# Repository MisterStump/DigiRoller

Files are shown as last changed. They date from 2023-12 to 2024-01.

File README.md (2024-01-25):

# DigiRoller

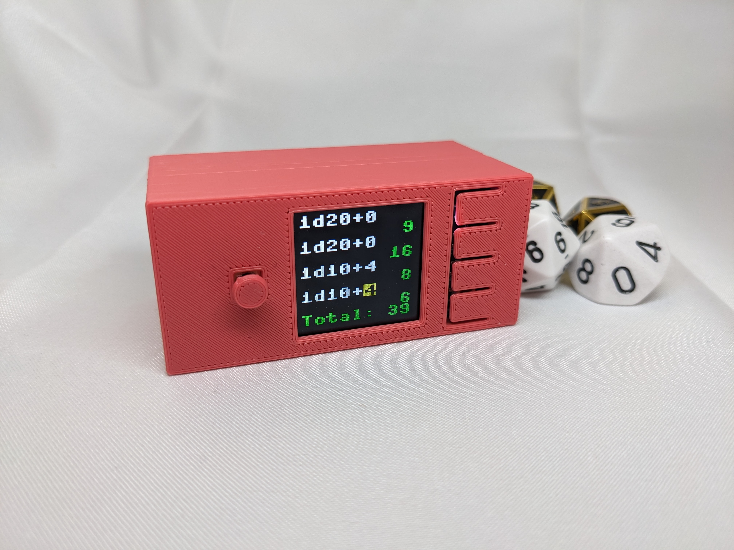
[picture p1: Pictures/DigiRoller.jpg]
DigiRoller


## What is it?
The DigiRoller is a Pico Pi powered pocket digital die roller designed for D&D/Tabletop gaming. Use it to make a handfull of simple rolls, or to roll a ton of dice all at once. I am posting this project because what got me into it was seeing all the other neat things people make. I wanted to maybe help inspire someone to try something too.

## How does it work?
There are 4 buttons, and a 4-way joystick
- Joytick up/down/left/right moves the cursor (the selection)
- First button rolls/rerolls
- Second button clears. If there are roll results those are cleared. If not, it resets all dice
- Third button increases the selected field
- Fourth button decreases the selected field

## Things you will need
- A 3D printer for the case
- A pico pi (https://www.waveshare.com/raspberry-pi-pico.htm)
- A pico 1.3" screen (https://www.waveshare.com/pico-lcd-1.3.htm)
- A pico USP power supply (https://www.waveshare.com/pico-ups-b.htm, the li-po one)

## Steps
- Once you have the pico, follow the instructions to set up Thonny so you can move code onto the pico: https://www.waveshare.com/wiki/Raspberry_Pi_Pico
- Move the 2 included .py files from the Code folder onto the pico
- Plug the screen in, following the guide: https://www.waveshare.com/wiki/Pico-LCD-1.3
- Plug the battery in, following the guide
- At this point, you should be able to unplug the Pico, turn on the UPS, and the battery roller code should work
- Now print the 3 case pieces.

## Print suggestions
I printed at a 0.2mm layer height. But each printer may have slightly different tolerances. You can use the Thingiverse Customizer for this project or the included OpenSCAD file to tweak the 'tolerance' settings.

## Final words
Good luck with the project!

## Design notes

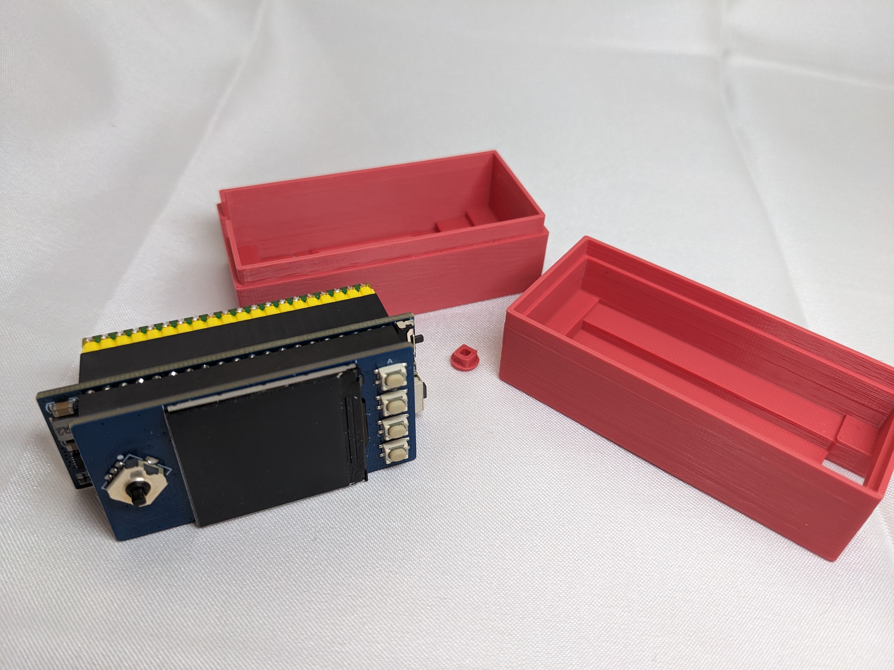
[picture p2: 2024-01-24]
Pictures/DigiRoller Bits.jpg

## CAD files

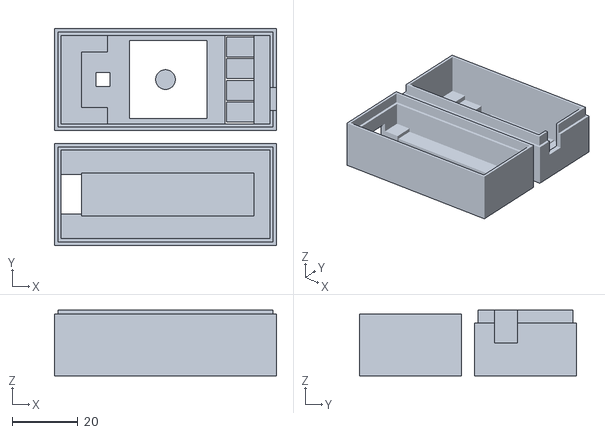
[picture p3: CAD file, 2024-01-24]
Case/all 3 pieces.stl
67.3 x 65.6 x 20.0

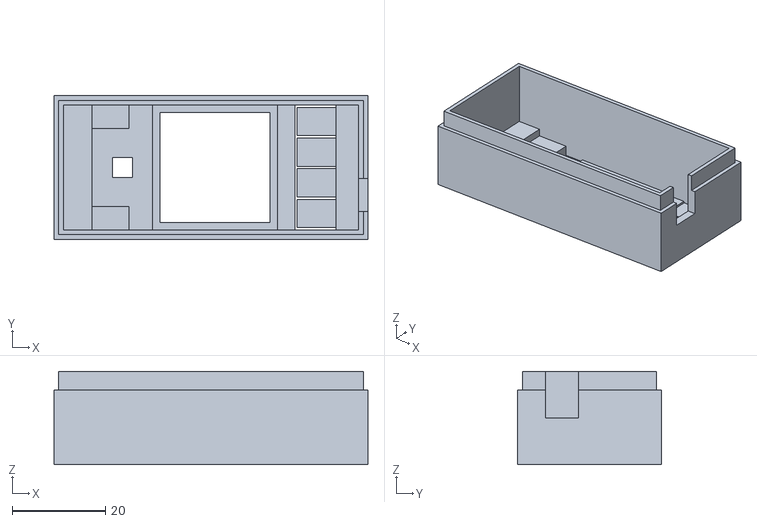
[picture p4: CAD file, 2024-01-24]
Case/top only.stl
67.3 x 30.8 x 20.0

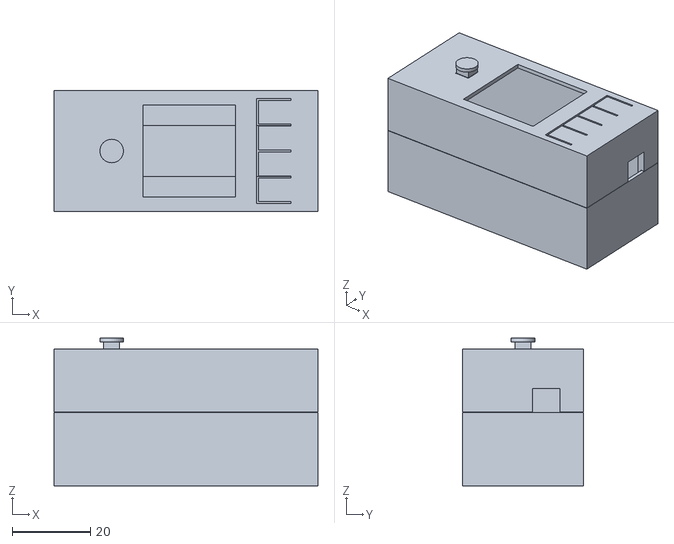
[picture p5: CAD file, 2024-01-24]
Case/demo - do not print.stl
67.3 x 30.8 x 37.7

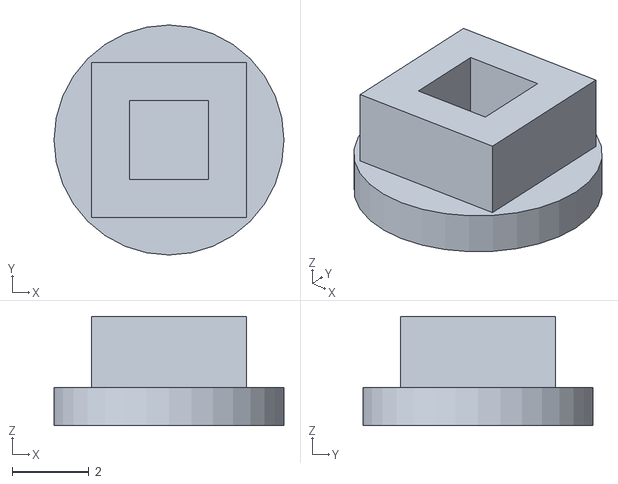
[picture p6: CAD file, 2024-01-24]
Case/joystick only.stl
6.00 x 6.00 x 2.85

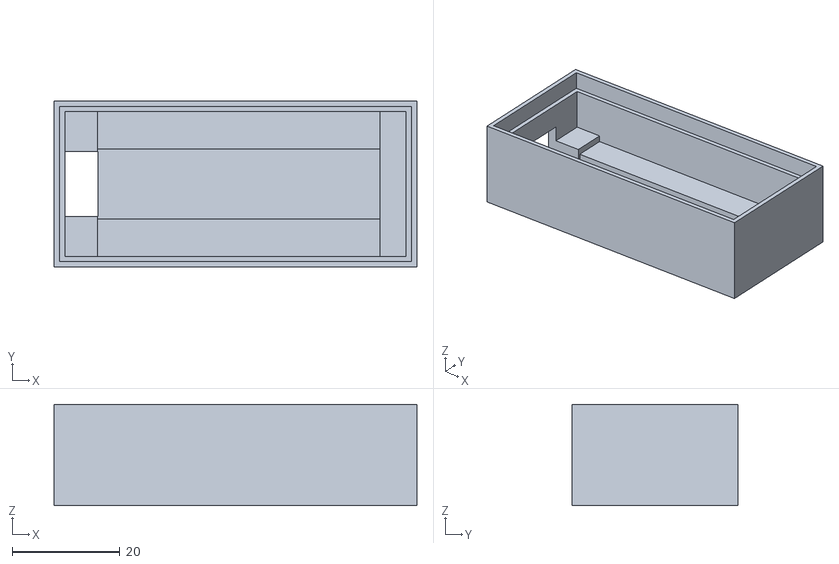
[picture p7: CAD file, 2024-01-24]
Case/bottom only.stl
67.3 x 30.8 x 18.8

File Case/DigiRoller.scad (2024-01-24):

// Digi Dice Roller - by MrStump
/*
Notes:
- Assuming you are looking head-on to the screen, then measurements are always:
    - x = left/right on screen
    - y = up/down on screen
    - z = the screen down to the battery back
- There are 3 models mentioned
    - Top Section = the upper body piece that includes the face
    - Bottom Section = the lower body piece that has the USB opening
    - Joystick = the little joystick nub that fits onto the 5-way switch
- Looking at the side, the module sections are:
    - ScreenSection = the screen all the way down to the UPS board
    - UPSSection = the battery board only, no pin sections
    - PicoSection = Everything below the UPS board, including the pin section
- The modules are oddly sided:
    - ScreenSection is larger in the Y than any other section
    - UPSSection is larger in the X than any other section
- The general layout of the code is:
    - Logic section determined what will be built and calls the Create module to make it
    - Create generates a whole printable piece using 1 or more Parts
    - Parts are individual fascets/conceptual elements of a model
*/


/////////////////////////////////////////////
// Parameters - things to modify to easilly change the model
/////////////////////////////////////////////

/* [General] */
//What part to print
Printed_Part = "All"; //[Top Section, Bottom Section, Joystick, All, Demo]
//How thick the face is. Impact look, as well as how stiff/flimsy buttons are
Face_Thickness = 0.6;
//How thickness of the thinnest part of walls
Wall_Thickness = 2;

/* [Tolerance offset so printed parts fit better] */
//How much X (left/right) to remove for the fitted parts
X_Tollerance = 0.3;
//How much Y (top of screen/bottom of screen) to remove for the fitted parts
Y_Tollerance = 0.3;
//How much Z (screen to back of case) to remove for the fitted parts
Z_Tollerance = 0.15;










//Prevents anything below this point showing in customizer
module customizerStop(){} customizerStop();


/////////////////////////////////////////////
// Hard-coded parameters - things to modify that are calculated or more delicate
/////////////////////////////////////////////

//Epsilon, prevent exact surface overlap during cutouts
eps = 0.007;
//Level of detail on rounded edges
$fn = 32;

//Measurements for the ScreenSection
//Circuit board measurements
ScreenSection_board_x = 52.25 + X_Tollerance;
ScreenSection_board_y = 26.52 + Y_Tollerance;
ScreenSection_board_z = 4.3;
//Pins (black plastic bit that connects ScreenSection to UPSSection)
ScreenSection_pins_x = 52.25 + X_Tollerance;
ScreenSection_pins_y = 20.15 + Y_Tollerance;
ScreenSection_pins_z = 9.8 - 0.45;

//Measurements for the UPSSection
//UPS board measurements (board only, not even counting circuits sticking up)
UPSSection_x = 63 + X_Tollerance;
UPSSection_y = 20.15 + Y_Tollerance;
UPSSection_z = 1.6 + Z_Tollerance;

//Max dimensions of interior space (where pico sits)
interiorMax_x = UPSSection_x;
interiorMax_y = ScreenSection_board_y;

//Measurements for the PicoSection
//Circuit board and circuits
PicoSection_board_x = 52.25 + X_Tollerance;
PicoSection_board_y = 20.95 + Y_Tollerance;
PicoSection_board_z = 2.8; //was 3.5
//Pins (black plastic bit that connects UPSSection to PicoSection)
PicoSection_pins_x = 52.25 + X_Tollerance;
PicoSection_pins_y = 20.95 + Y_Tollerance;
PicoSection_pins_z = 11.25;
//Amount above pins that the USB port is in the z
PicoSection_usb = 5.5; //THIS MAY BE WRONG
//Amount of upen air above the circuity
PicoSection_airGap_x = UPSSection_x;
PicoSection_airGap_y = 13; //in the center, this is the air space left
PicoSection_airGap_z = PicoSection_usb - PicoSection_board_z;

//UPS and Screen are not centered on the X. This is the additional excess
UPStoSCREEN_left = 6.11;
UPStoSCREEN_right = 4.88;
//Offset of Screen-To-UPS (it isn't quite centered on the X)
ScreenToUPSOffset_x = UPStoSCREEN_left - UPStoSCREEN_right - 0.6 + 0.2;

//Measurements of screen cutout
screenCut_x = 23.4 + X_Tollerance/2;
screenCut_y = 23.4 + Y_Tollerance/2;

//Measurements of joystick cutout
joyCut_x = 4 + X_Tollerance;
joyCut_y = 4 + Y_Tollerance;
//Distance from edge/center the joystick is positioned
joyCutDistance_fromEdge = 6.5;
joyCutDistance_fromCenter = ScreenSection_board_x/2 - joyCutDistance_fromEdge;

//Buttons X (y defined below)
button_x = 10;

//Space between each button
buttonCutWidth = 0.5;
//Measurements for buttons
buttonSecontion_x = button_x+buttonCutWidth;
buttonSecontion_y = ScreenSection_board_y;
//Distance from edge/center for the button positions
buttonSection_fromEdge = 4;
buttonSection_fromCenter = UPSSection_x/2 - buttonSecontion_x/2 - buttonSection_fromEdge;

//Button Y (x define above)
button_y = (buttonSecontion_y - (buttonCutWidth*5)) / 4;

//Joystick padding shape (to screen board, not UPS board)
joyPad_x = 8;
joyPad_y = 5;
joyPad_z = 2.5;

//Screen padding shape
screenPad_width = (ScreenSection_board_y - screenCut_y);
screenPad_x = screenCut_x + screenPad_width;
screenPad_y = screenCut_y + screenPad_width; 
screenPad_z = 0.5;

//Top section's walls, not including part that fits to bottom section
//X and Y don't include wall thickness
topWalls_x = UPSSection_x;
topWalls_y = ScreenSection_board_y;
topWalls_z = Face_Thickness + ScreenSection_board_z + ScreenSection_pins_z + UPSSection_z;

//Power switch cutouts (there are 2, 1 for switch and 1 for reset button)
switchCutout_insetFromSide = 4;
switchCutout_x = Wall_Thickness;
switchCutout_y = 7;
switchCutout_z = 6;

//Top iece Lip that connects to bottom piece's lip
topLip_x = topWalls_x;
topLip_y = topWalls_y;
topLip_z = 4;
topLip_thickness = Wall_Thickness/2;

//PicoSection's wall measurements (x and y doesn't include wallThickness)
botWalls_x = UPSSection_x;
botWalls_y = ScreenSection_board_y;
botWalls_z = Wall_Thickness + PicoSection_airGap_z + PicoSection_board_z + PicoSection_pins_z;

//Cutout for USB
usbCutout_x = Wall_Thickness + UPStoSCREEN_left;
usbCutout_y = 12;
usbCutout_z = Wall_Thickness + PicoSection_usb + 2;

//Bottom section lip that fits to top section lip to close case
//This is a cutout, while the top section's is addative
botLip_x = botWalls_x + Wall_Thickness; //removed x_tolerance due to looseness
botLip_y = botWalls_y + Wall_Thickness; //removed y_tolerance due to looseness
botLip_z = 4 - Z_Tollerance;

//Joystick wall/thumbpad thickness thickness
joy_thickness = 1;
//Joystick connector (inner dimensions)
//Tolerance is halved to get a tight fit
joyCon_x = 1.9 + X_Tollerance/2;
joyCon_y = 1.9 + Y_Tollerance/2;
joyCon_z = 1.7 + Z_Tollerance;
//Joystick thumbpad
joyPad_d = 6;

//Thickness of walls of connector for power switch and thickness of switch
power_thickness = 1;
//Power switch connector (inner dimensions)
//XYZ are oriented as if you are looking down at the switch, instead of the screen)
powerConnector_x = 1.52 + X_Tollerance/2;
powerConnector_y = 0.62 + Y_Tollerance/2;
powerConnector_z = 3.95 - power_thickness;
//Power switch botton (surface to grab)
powerSwitch_x = powerConnector_x + power_thickness*2;
powerSwitch_y = 5.8;
powerSwitch_z = power_thickness;



/////////////////////////////////////////////
// Logic - logic that determines what is made
/////////////////////////////////////////////

if (Printed_Part == "Top Section"){
    create_topSection();
}

else if (Printed_Part == "Bottom Section"){
    create_bottomSection();
}

else if (Printed_Part == "Joystick"){
    create_joystick();
}

else if (Printed_Part == "All"){
    yOffset = interiorMax_y/2 + Wall_Thickness*2;
    translate([0,yOffset,0])
    create_topSection();
    
    translate([0,-yOffset,0])
    create_bottomSection();
    
    translate([0,yOffset,0])
    create_joystick();
}

else if (Printed_Part == "Demo"){
    bottomToTop = botWalls_z+ScreenSection_board_z+ScreenSection_pins_z+UPSSection_z+Face_Thickness+0.1;
    translate([0,0,bottomToTop])
    rotate([180,0,0])
    create_topSection();
    
    translate([0,0,0])
    create_bottomSection();
    
    xOffset = -joyCutDistance_fromCenter+ScreenToUPSOffset_x;
    zOffset = bottomToTop + joy_thickness + joyCon_z;
    translate([xOffset,0,zOffset])
    rotate([180,0,0])
    create_joystick();
}







/////////////////////////////////////////////
// Create - Generate a whole piece of model
/////////////////////////////////////////////

//Create top section of model
module create_topSection(){
    union(){
        part_face();
        part_face_wallPad("left");
        part_face_wallPad("right");
        part_face_joyPads();
        part_face_screenPad();
        part_topSection_walls();
        part_topSection_lip();
    }
}
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

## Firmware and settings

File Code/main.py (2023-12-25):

# LCD interaction libraries
from lcd_lib import LCD_1inch3
from machine import Pin,SPI,PWM
# Random (for rolls)
import random



class DigiRoller():
    # Reference for screen drawing
    LCD = LCD_1inch3()
    # Hex colors got mixxed up in this library apparently, so these are not normal
    hex = {
        "black"   : 0x0000,
        "white"   : 0xFFFF,
        "red"     : 0x00F8,
        "yellow"  : 0xE0FF,
        "green"   : 0xE007
    }
    # Which dice types are available
    diceTypes = [4,6,8,10,12,20,100]
    # Order dice attributes are in
    attributeOrder = ["count", "type", "mod"]
    # Roll results get stored here, 1 for each die (when rolled)
    rollResults = []
    # Current selection default
    selectionData = {
        "die" : 1,
        "field": "count"
    }
    # Switches (buttons)
    switches = {
        "keyA"  : Pin(15,Pin.IN,Pin.PULL_UP),
        "keyB"  : Pin(17,Pin.IN,Pin.PULL_UP),
        "keyX"  : Pin(19 ,Pin.IN,Pin.PULL_UP),
        "keyY"  : Pin(21 ,Pin.IN,Pin.PULL_UP),
        "up"    : Pin(2,Pin.IN,Pin.PULL_UP),
        "down"  : Pin(18,Pin.IN,Pin.PULL_UP),
        "left"  : Pin(16,Pin.IN,Pin.PULL_UP),
        "right" : Pin(20,Pin.IN,Pin.PULL_UP),
        "ctrl"  : Pin(3,Pin.IN,Pin.PULL_UP)
    }
    # Object that will hold keypress observers. 1 = unpressed, 0 = pressed
    toggleWatch = {}
    for k in switches.keys():
        toggleWatch[k] = 1
           
    def __init__(self):
        #Establish a blank diceData to hold die settings
        self.clearDiceData()
        #Establish blank selection data
        self.clearSelectionData()
        
        #What functions each key activates
        self.buttonFunctions = {
            "keyA"  : self.buttonPress_keyA,
            "keyB"  : self.buttonPress_keyB,
            "keyX"  : self.buttonPress_keyX,
            "keyY"  : self.buttonPress_keyY,
            "up"    : self.buttonPress_up,
            "down"  : self.buttonPress_down,
            "left"  : self.buttonPress_left,
            "right" : self.buttonPress_right,
            "ctrl"  : self.buttonPress_ctrl
        } 
        
        #Draw initial screen and start running loop to listen for buttons
        self.redrawScreen()
        self.buttonMonitoringLoop()
    
    
    # Creates the dice data object. Is reset to these values when cleared
    def clearDiceData(self):
        self.diceData = [
            {
                "count" : 1,
                "type" : 8,
                "mod" : 0
            },
            {
                "count" : 0,
                "type" : 8,
                "mod" : 0
            },
            {
                "count" : 0,
                "type" : 8,
                "mod" : 0
            },
            {
                "count" : 0,
                "type" : 8,
                "mod" : 0
            }
        ]
    # Clears the selection object
    def clearSelectionData(self):
        self.selectionData = {
            "die" : 1,
            "field": "count"
        }
    
    
    # X coord based on desired character position
    @staticmethod
    def getX(col):
        offset = 10
        charSize = 24
        i = col-1
        return offset + (charSize * i)
    # Y coord based on desired character position
    @staticmethod
    def getY(row):
        offset = 10
        charSize = 24
        i = row-1
        return offset + (charSize * i)
    # what column # is needed for getX (handles 1 to 2 dynamic digit counts)
    @staticmethod
    def getFieldCol(field, dieData):
        if (field=="count"):
            return 1
        elif (field=="d"):
            len_count = len(str(dieData["count"]))
            return len_count + 1
        elif (field=="type"):
            len_count = len(str(dieData["count"]))
            return len_count + 2
        elif (field=="+"):
            len_count = len(str(dieData["count"]))
            len_type = len(str(dieData["type"]))
            return len_count + len_type + 2
        elif (field=="mod"):
            len_count = len(str(dieData["count"]))
            len_type = len(str(dieData["type"]))
            return len_count + len_type + 3
    
    
    def redrawScreen(self):
        #Clear screen
        self.LCD.fill(self.hex['black'])
        
        #Draw roll request to screen
        for rowIndex, dieData in enumerate(self.diceData):        
            #Print roll request
            dieNumber = rowIndex+1
            self.drawRollRequest(dieNumber, dieData)
            #print roll result
            if (len(self.rollResults) > 0):
                self.drawRollResult(dieNumber, dieData)
            
        #Print result total
        if (len(self.rollResults) > 0):
            self.drawRollResultTotal()
        
        #Display redrawn image
        self.LCD.show()
        
    
    
    # Draw the given roll request on a given row (1d6+0)
    def drawRollRequest(self, dieNumber, dieData):
        #Line this roll request goes on
        rowForText = dieNumber + dieNumber - 1
        #Is this line selected
        isThisLineSelected = self.selectionData["die"] == dieNumber

        #Draw selection indicator
        if (isThisLineSelected):
            selectionCol = self.getFieldCol(self.selectionData["field"], dieData)
            selectionSize = len(str(abs(dieData[self.selectionData["field"]])))
            for i in range(0,selectionSize):
                self.LCD.fill_rect(
                    self.getX(selectionCol+i),
                    self.getY(rowForText)-2,
                    24,
                    24,
                    self.hex["yellow"])
        
        #Write text
        #Define result sections
        drawTextElements = ["count", "d", "type", "+", "mod"]
        #add in d and + into the die info. They are static/logic determined
        dieData["d"] = "d"
        dieData["+"] = "+" if dieData["mod"]>=0 else "-"
        #Write each section to its line
        for textElement in drawTextElements:
            isThisElementSelected =  self.selectionData["field"]==textElement if (isThisLineSelected) else False
            textColor = self.hex["white"] if (not isThisElementSelected) else self.hex["black"]
            self.LCD.write_text(
                dieData[textElement] if type(dieData[textElement])==str else str(abs(dieData[textElement])),
                x=self.getX(self.getFieldCol(textElement, dieData)),
                y=self.getY(rowForText),
                size=3,
                color=textColor)
            
    # Draw roll results
    def drawRollResult(self, dieNumber, dieData):
        rowForText = dieNumber + dieNumber
        result = self.rollResults[dieNumber-1]
        resultLength = len(str(result))
        
        #Write result to far right of screen
        if (dieData["count"] > 0):
            self.LCD.write_text(
                str(result),
                x=self.getX(10-resultLength),
                y=self.getY(rowForText),
                size=3,
                color=self.hex["green"])
        
    #Draw total of roll results
    def drawRollResultTotal(self):
        total = sum(self.rollResults)
        totalLength = len(str(total))
        #Write 'total'
        self.LCD.write_text(
            "Total:",
            x=self.getX(1),
            y=self.getY(9),
            size=3,
            color=self.hex["green"])
        #Write total        
        self.LCD.write_text(
            str(total),
            x=self.getX(10-totalLength),
            y=self.getY(9),
            size=3,
            color=self.hex["green"])

    def buttonMonitoringLoop(self):
        # Loop for duration of script device on state
        while(1):
            # Loop over each switch and determine if a button is pressed
            for switchName, switchRef in self.switches.items():
                previousSwitchVal = self.toggleWatch[switchName] #last loop val
                self.toggleWatch[switchName] = switchRef.value() #overwrite last with current
                newSwitchVal = self.toggleWatch[switchName] #tidy variable name new value
                
                #Trigger on switch being depressed
                #To switch so it triggers on button release instead, switch the 1 and 0
                if (newSwitchVal == 0 and previousSwitchVal == 1):
                    #print(f"You pressed '{switchName}'")
                    self.buttonFunctions[switchName]()
                    self.redrawScreen()
                
    
    #Button press functions
    def buttonPress_keyA(self):
        # Clear any previous roll results
        self.rollResults = []
        # Loop over each die
        for dieData in self.diceData:
            # Roll each die 'count' many times and record each roll
            allRollResults = []
            for _ in range(0,dieData["count"]):
                allRollResults.append(random.randint(1,dieData["type"]))
            print(allRollResults)
            # Add together results and record to rollResults                          
            resultWithMod =   sum(allRollResults) + dieData["mod"]
            self.rollResults.append(resultWithMod)                           
    
    def buttonPress_keyB(self):
        # Clear diceData
        if (len(self.rollResults)==0):
            self.clearDiceData()
            self.clearSelectionData()
        # Clear roll results
        self.rollResults = []
    
    #Increment up
    def buttonPress_keyX(self):
        curDieIndex = self.selectionData["die"]-1
        curDieField = self.selectionData["field"]
        if (curDieField=="count" or curDieField=="mod"):
            self.diceData[curDieIndex][curDieField] += 1
        elif (curDieField=="type"):
            maxDieTypes = len(self.diceTypes)
            currentDieTypeIndex = self.diceTypes.index(self.diceData[curDieIndex][curDieField])
            if (currentDieTypeIndex < maxDieTypes-1):
                self.diceData[curDieIndex][curDieField] = self.diceTypes[currentDieTypeIndex+1]
    
    #Increment down
    def buttonPress_keyY(self):
        curDieIndex = self.selectionData["die"]-1
        curDieField = self.selectionData["field"]
        if (curDieField=="count"):
            if (self.diceData[curDieIndex][curDieField] > 0):
                self.diceData[curDieIndex][curDieField] -= 1
        elif (curDieField=="mod"):
            self.diceData[curDieIndex][curDieField] -= 1
        elif (curDieField=="type"):
            currentDieTypeIndex = self.diceTypes.index(self.diceData[curDieIndex][curDieField])
            if (currentDieTypeIndex > 0):
                self.diceData[curDieIndex][curDieField] = self.diceTypes[currentDieTypeIndex-1]
    
    #Move selection up
    def buttonPress_up(self):
        curDie = self.selectionData["die"]
        if (curDie > 1):
            self.selectionData["die"] = curDie-1
    
    #Move selection down
    def buttonPress_down(self):
        curDie = self.selectionData["die"]
        maxDice = len(self.diceData)
        if (curDie < maxDice):
            self.selectionData["die"] = curDie+1
    
    #Move selection left
    def buttonPress_left(self):
        curField = self.selectionData["field"]
        curIndex = self.attributeOrder.index(curField)
        if (curIndex > 0):
            nextField = self.attributeOrder[curIndex-1]
            self.selectionData["field"] = nextField
    
    #Move selection right
    def buttonPress_right(self):
        curField = self.selectionData["field"]
        curIndex = self.attributeOrder.index(curField)
        if (curIndex < 2):
            nextField = self.attributeOrder[curIndex+1]
            self.selectionData["field"] = nextField
        
    def buttonPress_ctrl(self):
        pass
    
        """     
        # Order dice attributes are in
        attributeOrder = ["count", "type", "mod"]
        # Default dice data
        diceData = [
            {
                "count" : 2,
                "type" : 6,
                "mod" : 3
            },
            {
                "count" : 10,
                "type" : 20,
                "mod" : 10
            },
            {
                "count" : 1,
                "type" : 20,
                "mod" : -3
            },
            {
                "count" : 1,
                "type" : 8,
                "mod" : 0
            }
        ]
        # Current selection default
        selectionData = {
            "die" : 1,
            "field": "count"
        }
        """




DR = DigiRoller()
